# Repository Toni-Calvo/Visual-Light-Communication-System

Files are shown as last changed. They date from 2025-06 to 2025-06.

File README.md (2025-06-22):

# 📡 Visual Light Communication System

A visual light communication system developed and designed to be used as ambient light. It uses two Arduinos to modulate and demodulate light transmissions at a high frequency so the user does not experience light flickering. This system can be used in any building requiring Wi-Fi coverage where structural layouts create areas with poor signal.

---

## 📋 How to Use

To use the system, upload the file `transmitter\tx_code\tx_code.ino` to one Arduino and the file `receiver\rx_code\rx_code.ino` to another. Then, follow one of two options to build the transmitter and receiver modules:

---

### __1. Using a PCB Model:__
To use a PCB model, utilize the fabrication files located under `transmitter\transmitter_board\fab_files` and `receiver\receiver_board\fab_files` to build both boards:

**<u>Transmitter Board:</u>**

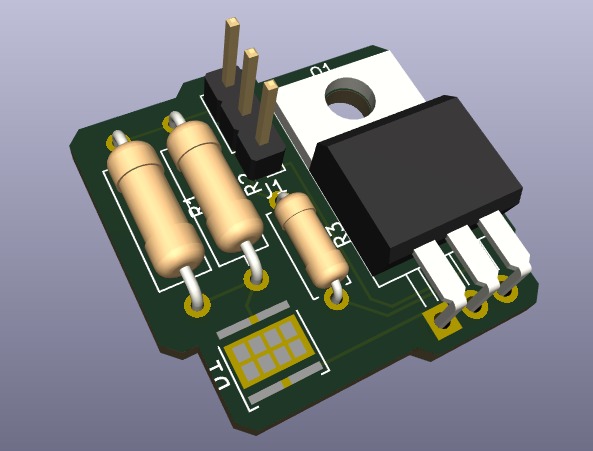
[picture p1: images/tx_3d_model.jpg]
Transmitter Board 3D Model


The pins on the PCB are, from top to bottom: Power, Ground, and Signal. The signal pin connects to Arduino digital pin 13.

**<u>Receiver Board:</u>**

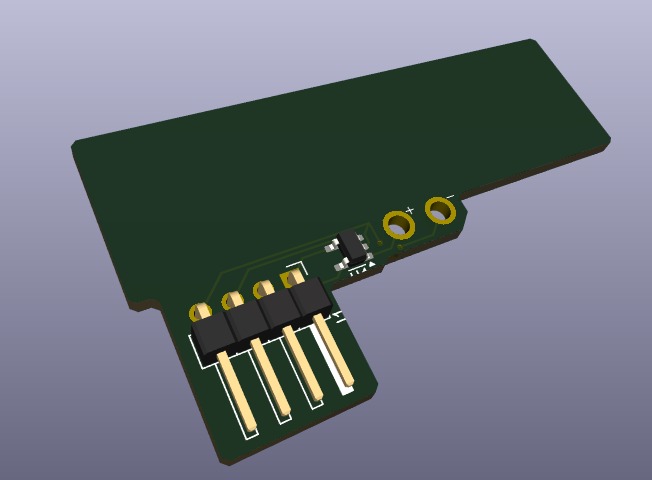
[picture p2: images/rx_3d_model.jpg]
Receiver Board 3D Model


The receiver module requires a solar panel on the empty slot at the top. The pins on the PCB are, from left to right: Ground, Power (1V), Power (5V), and Signal. The signal pin connects to Arduino digital pin 2.

---

### __2. Building Your Own Module:__

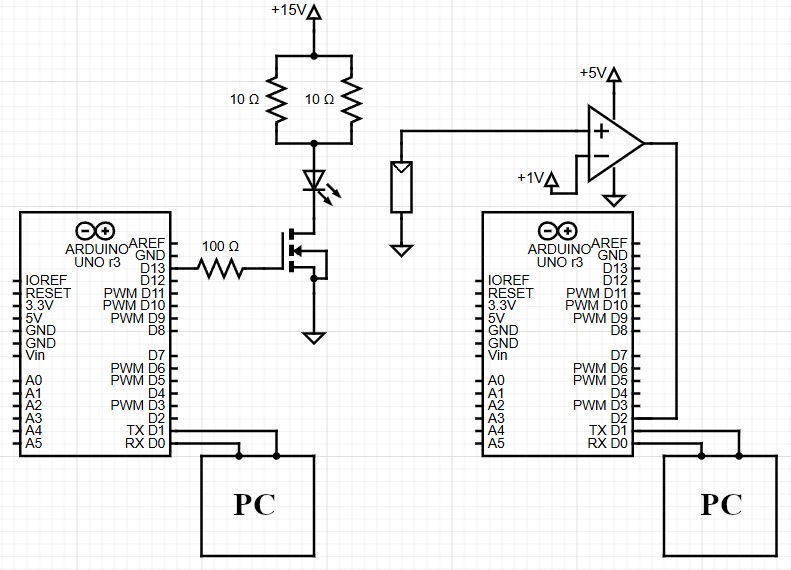
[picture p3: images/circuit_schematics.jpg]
Circuit Schematic


By following the schematics, you can build the circuit on a protoboard or similar (this is how we tested our system).

> [!WARNING]
> Ensure that both 10Ω resistors in the transmitter module (left) are rated to withstand the required power without overheating.

Once everything is connected, start both Arduinos. Any message written through the serial port of the transmitter Arduino will be displayed through the serial port of the receiver Arduino.

> [!NOTE]
> The modulation algorithm is designed to work with individual uppercase and lowercase alphabetical characters, so words are transmitted character by character.

> [!CAUTION]
> If no data is received, or the data received is not the same as the one sent, ensure the solar panel receives sufficient light from the LED and that ambient light, such as solar, is not interfering.

---

## 🔮 Future Improvements
* Add the possibility to regulate the light intensity (Pulse Duty Cycle).
* Allow bidirectional communication.
* Enable the transmission of non-alphabetical characters.
* Test the system with more than one receiver.
* Add protocols for data transmission to increase the complexity and scale of the system.

---

## ⚖ License
MIT License 2025 - [Toni Calvo Belmonte](https://github.com/Toni-Calvo). Take a look at the [LICENSE.md](LICENSE.md) for more information.

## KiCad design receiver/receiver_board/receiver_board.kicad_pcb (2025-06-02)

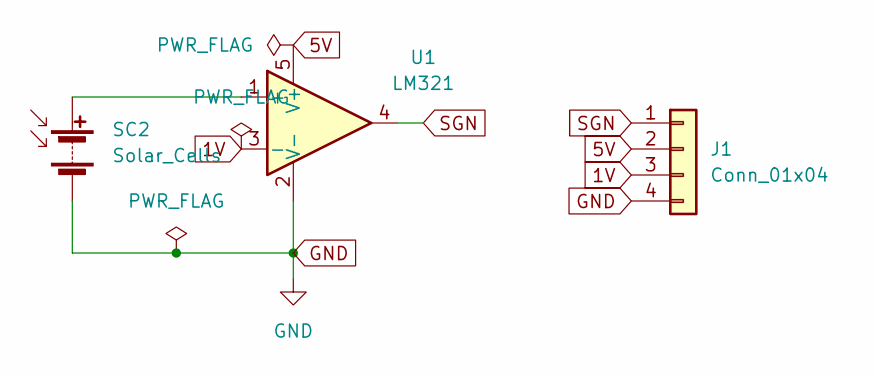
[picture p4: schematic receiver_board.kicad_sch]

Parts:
J1: Conn_01x04; PinHeader_1x04_P2.54mm_Horizontal
SC2: Solar_Cells; SolarCell_15mmx50mm_4PAD
U1: LM321; SOT-23-5

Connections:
1V: J1.3, U1.3 (-)
5V: J1.2, U1.5 (V+)
GND: J1.4, SC2.2 (-), U1.2 (V-)
unnamed: SC2.1 (+), U1.1 (+)
SGN: J1.1, U1.4

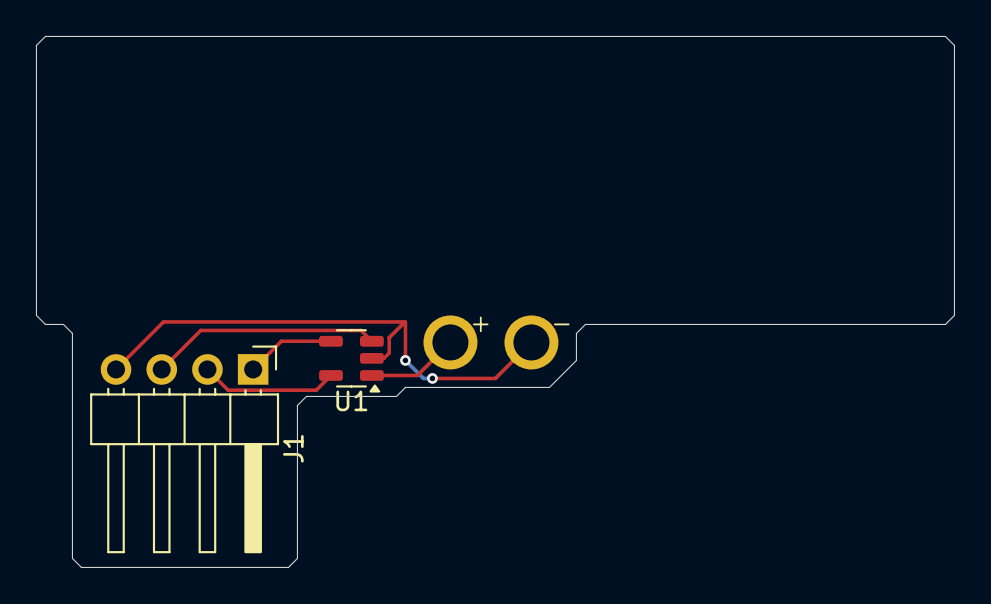
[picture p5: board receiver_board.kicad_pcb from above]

Board: 2 copper layers, 51.0 x 29.5 mm, 3 parts (0 on the bottom side), 5 nets.

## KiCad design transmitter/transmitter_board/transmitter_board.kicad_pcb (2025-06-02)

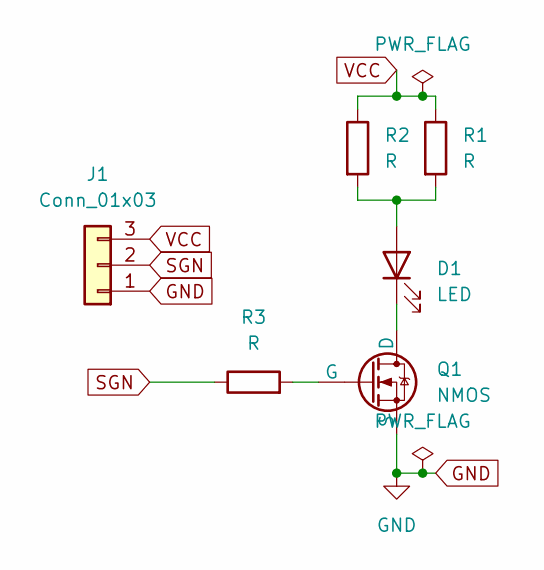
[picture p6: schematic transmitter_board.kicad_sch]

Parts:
D1: LED; LED_Cree-XHP50_6V
J1: Conn_01x03; PinHeader_1x03_P2.54mm_Vertical
Q1: NMOS; TO-220-3_Horizontal_TabDown
R1, R2: R; R_Axial_DIN0309_L9.0mm_D3.2mm_P12.70mm_Horizontal
R3: R; R_Axial_DIN0207_L6.3mm_D2.5mm_P7.62mm_Horizontal

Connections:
GND: J1.1, Q1.3 (S)
unnamed: D1.2 (A), R1.2, R2.2
unnamed: D1.1 (K), Q1.1 (D)
unnamed: Q1.2 (G), R3.2
SGN: J1.2, R3.1
VCC: J1.3, R1.1, R2.1

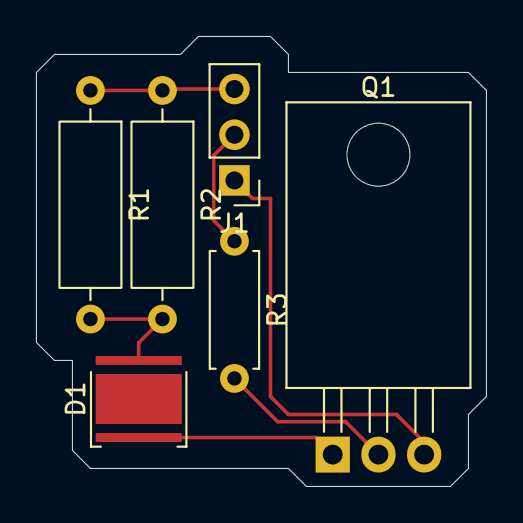
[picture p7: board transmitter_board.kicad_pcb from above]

Board: 2 copper layers, 25.0 x 25.0 mm, 6 parts (0 on the bottom side), 6 nets.

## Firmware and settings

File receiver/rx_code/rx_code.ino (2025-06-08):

const int bit_duration = 10000; // us
const int idle_duration = bit_duration * 3/8;      // maximum time for the bit start HIGH state
const int same_bit_duration = bit_duration * 3/4;  // maximum time for a state (H or L) of the same bit

unsigned long dt;           // delta time (time between edges)
unsigned long last_change;  // time stamp of the last edge
bool change = false;        // input chaged (H-L or L-H)
bool idle = true;           // idle state (no transmission)
bool save = false;          // save state (transmission)
int last_bit = 0;           // last bit detected (0: "0", 1: "1", 2: "bit start")
bool data[8];               // saved data
int bit_index;              // index of current transmission bit

void setup() {
  // Initialization

  Serial.begin(9600);
  pinMode(2, INPUT);
  attachInterrupt(digitalPinToInterrupt(2), handlePinChange, CHANGE);
  while(!Serial) {;}
  Serial.println("RX Ready");
  dt = 0;
  last_change = micros();
}

void loop() {
  // Logic Block

  if (change) {
    if (idle) {
      if (dt < idle_duration) {
        // Detects the first pulse of the bit start

        idle = false;
        last_bit = 2;
      }
    }
    else {
      if (save) {
        // Saves the bits into data

        if (last_bit == 0) {
          if (dt < same_bit_duration) { 
            // SAVE "0"
            data[bit_index] = last_bit;
            last_bit = 0;
          }
          else {  
            // SAVE "1"
            data[bit_index] = last_bit;
            last_bit = 1;
          }
          
          bit_index++;
        }
        else if (last_bit == 1) {
          if (dt < same_bit_duration) { 
            // SAVE "1"
            data[bit_index] = last_bit;
            last_bit = 1;
          }
          else {  
            // SAVE "0"
            data[bit_index] = last_bit;
            last_bit = 0;
          }
          
          bit_index++;
        }
      }
      else {
        if (dt < idle_duration){
          // Detects the second pulse of the bit start and starts the save state

          save = true;
          last_bit = 0; // first bit is always 0 for alphabetic characters in ASCII
          bit_index = 0;
        }
        else {
          // Return to idle state

          idle = true;
        }
      }

      if (bit_index == 8) {
        // Transmission has finished
        
        idle = true;
        save = false;
        Serial.print("Character: ");
        byte ascii = 0;
        for (int i = 0; i < 8; i++) {
          if (data[i]) {
            ascii |= (1 << (7 - i));
            Serial.print(1);
          }
          else {
            Serial.print(0);
          }
        }
        Serial.print(" ");
        Serial.println((char)ascii);
      }
    }
    change = false;
  }
}


void handlePinChange() {
  // Detects rising and falling edges and triggers the change flag to detect if its a "0" or a "1"

  int pin_state = digitalRead(2);

  if ((last_bit != 1 && pin_state == LOW) || (last_bit == 1 && pin_state == HIGH)) {
    // Triggers change flag to start the logic block in loop

    dt = micros() - last_change;
    change = true;
  }

  last_change = micros();
}

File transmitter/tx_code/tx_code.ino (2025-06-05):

const int bit_duration = 10000; // us
const int half_bit_duration = bit_duration / 2;
const int quarter_bit_duration = bit_duration / 4;
char data;            // transmission data
bool tx;              // transmitting flag
unsigned long time;   // time between pulse start and logic
int offset = 3;       // bits between transmission


void setup() {
  // Initialization

  Serial.begin(9600);
  pinMode(13, OUTPUT);
  tx = false;
  while (!Serial) {;}
  Serial.println("TX Ready");
}


void loop() {
  if (tx) {
    // start transmission

    sendData();
    tx = false;
  }
  else {
    // no transmission

    sendBit(0);
    time = micros();
    tx = getData();   // check for wanted transmissions
    delayMicroseconds(half_bit_duration - micros() + time);
  } 
}


void sendBit(int bit) {
  // Sends a bit through the channel

  if (bit == 0) {
    digitalWrite(13, LOW);
    delayMicroseconds(half_bit_duration);
    digitalWrite(13, HIGH);
  }
  else {
    digitalWrite(13, HIGH);
    delayMicroseconds(half_bit_duration);
    digitalWrite(13, LOW);
  }
}


bool getData() {
  // Checks if the user wants to transmit data

  if (Serial.available() > 0 && offset == 0) {
    // data found

    offset = 3;
    data = Serial.read();
    Serial.print("Character '");
    Serial.print(data);
    Serial.println("'");
    return true;
  }
  if (offset != 0) {
    // delay between bytes

    offset--;
  }

  return false;
}


void sendData() {
  // Sends the character in data through the channel

  startSequence();
  
  for (int i = 7; i >= 0; i--) {
    if ((data >> i) & 0x01) {
      // sends bit 1

      sendBit(1);
      Serial.print("1");
      delayMicroseconds(half_bit_duration);
    }
    else {
      // sends bit 0

      sendBit(0);
      Serial.print("0");
      delayMicroseconds(half_bit_duration);
    }
  }
  Serial.println();
}


void startSequence() {
  // Sends the start sequence (bit start)

  digitalWrite(13, LOW);
  delayMicroseconds(quarter_bit_duration);
  digitalWrite(13, HIGH);
  delayMicroseconds(quarter_bit_duration);
  digitalWrite(13, LOW);
  delayMicroseconds(quarter_bit_duration);
  digitalWrite(13, HIGH);
  delayMicroseconds(quarter_bit_duration);
}

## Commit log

2025-06-02 Transmitter Board
    Created the schematics for the transmitter board in kicad
    [transmitter_board-B_Cu.gbr, transmitter_board-B_Mask.gbr, transmitter_board-B_Paste.gbr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]
2025-06-02 Receiver Board
    Created the schematics for the receiver board in KiCad.
    [receiver_board-B_Cu.gbr, receiver_board-B_Mask.gbr, receiver_board-B_Paste.gbr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]
2025-06-05 Re-Ordered components in PCB
    Moved components in KiCad to better view them.
    [receiver_board.kicad_sch, transmitter_board.kicad_sch]
2025-06-05 Transmitter Code
    Created the code for the arduino modulating the signals.
